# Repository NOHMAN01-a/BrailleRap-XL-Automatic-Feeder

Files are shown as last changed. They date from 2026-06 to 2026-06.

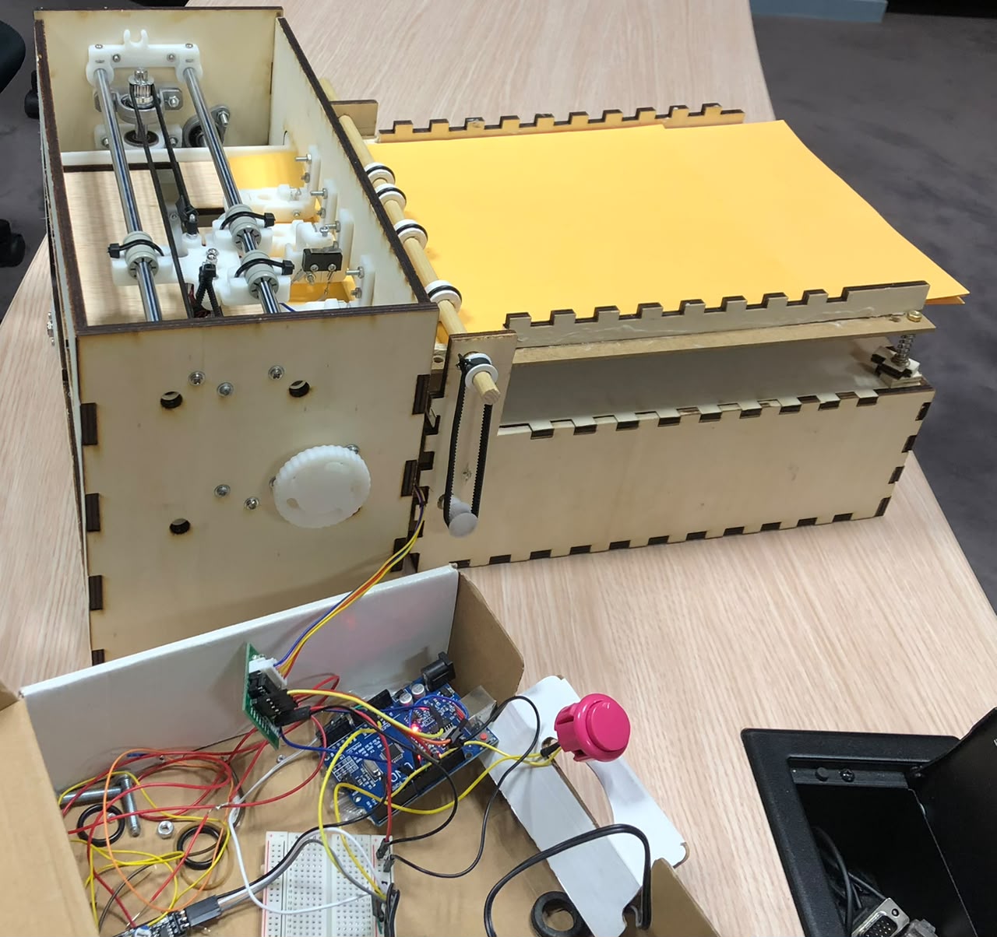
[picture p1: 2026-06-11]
WhatsApp Image 2026-06-10 at 10.59.23 AM (2).jpeg

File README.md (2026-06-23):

# BrailleRap XL Automatic Feeder

Projet réalisé dans le cadre du stage de Master EEA à l'ISTIC - Université de Rennes.

## Travaux réalisés

- Assemblage de la BrailleRap L
- Validation expérimentale sur banc de test
- Optimisation des paramètres de déplacement
- Développement d'un chargeur automatique de feuilles

## Système développé

Le chargeur automatique est constitué :

- d'une carte Arduino ;
- d'un moteur pas à pas 28BYJ-48 ;
- d'un driver ULN2003 ;
- d'un capteur infrarouge de détection ;
- d'un bouton poussoir ;
- d'un rouleau d'entraînement imprimé en 3D ;
- de poulies imprimées en 3D ;
- d'un support en bois découpé au laser ;
- de quatre ressorts assurant la compensation de hauteur de la pile de feuilles.

## Fonctionnement

1. L'utilisateur appuie sur le bouton.
2. Le moteur entraîne le rouleau.
3. La feuille avance vers la BrailleRap L.
4. Le capteur détecte l'arrivée de la feuille.
5. L'Arduino arrête automatiquement le moteur.

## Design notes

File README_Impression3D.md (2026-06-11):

# Pièces imprimées en 3D

## Objectif

Plusieurs composants mécaniques du chargeur automatique ont été réalisés par impression 3D afin de réduire le coût de fabrication et de faciliter les modifications du prototype.

## Composants réalisés

### Rouleau d'entraînement

Le rouleau d'entraînement a été modélisé sous Tinkercad puis fabriqué par impression 3D.

Sa fonction est d'assurer l'entraînement des feuilles vers l'entrée de la BrailleRap XL.

Des joints toriques ont été ajoutés afin d'augmenter l'adhérence entre le rouleau et les feuilles.

### Poulies

Les poulies utilisées pour la transmission du mouvement ont également été modélisées sous Tinkercad puis imprimées en 3D.

Elles permettent de transmettre efficacement le mouvement du moteur vers le rouleau d'entraînement.

### Supports mécaniques

Certaines pièces de fixation et de guidage ont également été réalisées par impression 3D afin de faciliter l'intégration du système au sein du chargeur automatique.

## Avantages de l'impression 3D

L'utilisation de l'impression 3D a permis :

* une fabrication rapide des prototypes ;
* des modifications simples entre les différentes versions ;
* un coût de réalisation réduit ;
* une personnalisation adaptée aux besoins du projet.

## Logiciel utilisé

Les modèles 3D ont été réalisés sous Tinkercad avant leur fabrication par impression 3D.

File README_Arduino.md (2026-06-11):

# Commande Arduino du chargeur automatique

## Composants utilisés

Arduino UNO
 Moteur pas à pas 28BYJ-48
 Driver ULN2003
 Capteur infrarouge de détection
 Bouton poussoir
 Alimentation 5 V

## Connexions

### Bouton poussoir

 Composant | Arduino 
  
 Bouton     D2      
 Bouton     GND     

### Capteur infrarouge

 Capteur  Arduino 
 -------  ------- 
 VCC      5V      
 GND      GND     
 OUT      D3      

### Driver ULN2003

 ULN2003 | Arduino 
 -------  -------
 IN1      D8      
 IN2      D10     
 IN3      D9      
 IN4      D11     

Le moteur 28BYJ-48 est directement connecté au driver ULN2003.

## Principe de fonctionnement

Le système fonctionne selon la séquence suivante :

1. L'utilisateur appuie sur le bouton poussoir.
2. L'Arduino démarre le moteur pas à pas.
3. Le rouleau entraîne une feuille vers l'entrée de la BrailleRap XL.
4. Lorsque la feuille atteint la position souhaitée, le capteur infrarouge la détecte.
5. L'Arduino arrête immédiatement le moteur.
6. La feuille est alors correctement positionnée pour l'impression.

## Description du programme

Le programme utilise la bibliothèque Stepper pour piloter le moteur pas à pas.

Le bouton poussoir permet de lancer un cycle d'alimentation. Une boucle surveille ensuite l'état du capteur infrarouge.

Tant qu'aucune feuille n'est détectée, le moteur continue de tourner. Dès que le capteur détecte la présence de la feuille, l'Arduino arrête le moteur afin de positionner correctement le papier à l'entrée de la machine.

Cette stratégie simple a permis d'obtenir une alimentation feuille par feuille fiable lors des essais réalisés sur le prototype.

## Explication du code

### Bibliothèque Stepper

```cpp
#include <Stepper.h>
```

Permet de piloter le moteur pas à pas à l'aide de la bibliothèque Arduino Stepper.

---

### Nombre de pas du moteur

```cpp
const int stepsPerRevolution = 2048;
```

Définit le nombre de pas nécessaires pour effectuer un tour complet du moteur 28BYJ-48.

---

### Déclaration du moteur

```cpp
Stepper myStepper(stepsPerRevolution, 8, 10, 9, 11);
```

Associe le moteur aux broches de commande du driver ULN2003.

---

### Déclaration des entrées

```cpp
const int buttonPin = 2;
const int sensorPin = 3;
```

Déclare les broches utilisées respectivement pour le bouton poussoir et le capteur infrarouge.

---

### Variable de mémorisation

```cpp
bool lastButtonState = HIGH;
```

Permet de mémoriser l'état précédent du bouton afin de détecter un nouvel appui.

---

### Fonction setup()

```cpp
void setup()
```

Fonction exécutée une seule fois au démarrage de l'Arduino.

```cpp
pinMode(buttonPin, INPUT_PULLUP);
```

Configure le bouton poussoir en entrée avec résistance interne.

```cpp
pinMode(sensorPin, INPUT);
```

Configure le capteur infrarouge en entrée.

```cpp
myStepper.setSpeed(10);
```

Définit la vitesse de rotation du moteur.

---

### Fonction loop()

```cpp
void loop()
```

Fonction exécutée en continu pendant le fonctionnement du système.

---

### Lecture du bouton

```cpp
bool currentButtonState = digitalRead(buttonPin);
```

Lit l'état actuel du bouton poussoir.

---

### Détection d'un appui

```cpp
if (lastButtonState == HIGH && currentButtonState == LOW)
```

Détecte un nouvel appui sur le bouton.

---

### Rotation du moteur

```cpp
while (digitalRead(sensorPin) == HIGH)
{
    myStepper.step(10);
}
```

Le moteur tourne tant que le capteur ne détecte pas la présence d'une feuille.

---

### Détection de la feuille

```cpp
digitalRead(sensorPin)
```

Lit l'état du capteur infrarouge.

* HIGH : aucune feuille détectée.
* LOW : feuille détectée.

---

### Arrêt du moteur

Lorsque le capteur détecte la feuille, la boucle s'arrête automatiquement et le moteur cesse de tourner.

---

### Temporisation

```cpp
delay(300);
```

Ajoute une courte temporisation afin d'éviter plusieurs déclenchements successifs.

---

### Mise à jour de l'état du bouton

```cpp
lastButtonState = currentButtonState;
```

Met à jour l'état précédent du bouton pour préparer le cycle suivant.

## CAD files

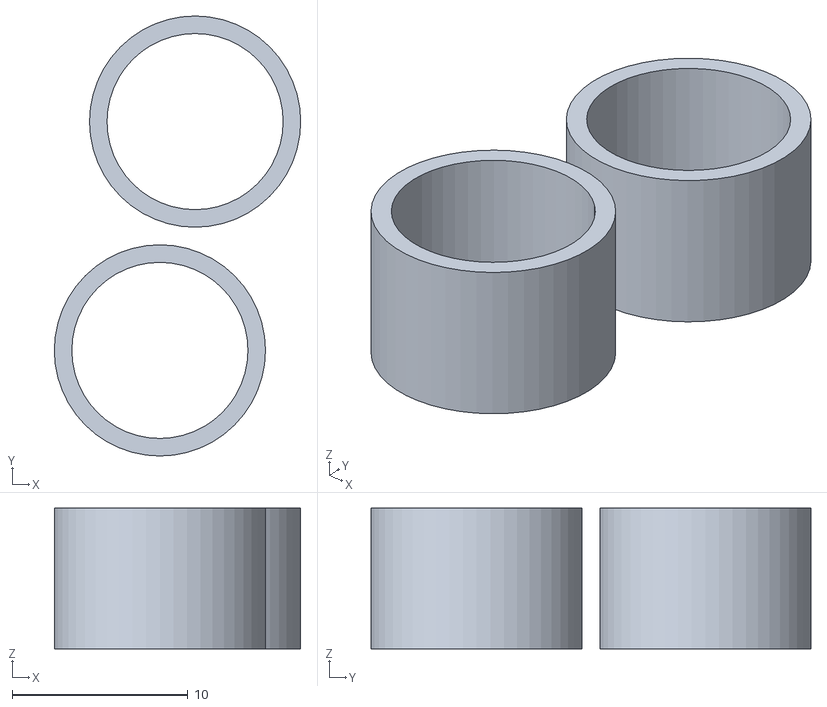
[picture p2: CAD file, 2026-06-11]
cylindre.stl
14.0 x 25.0 x 8.00

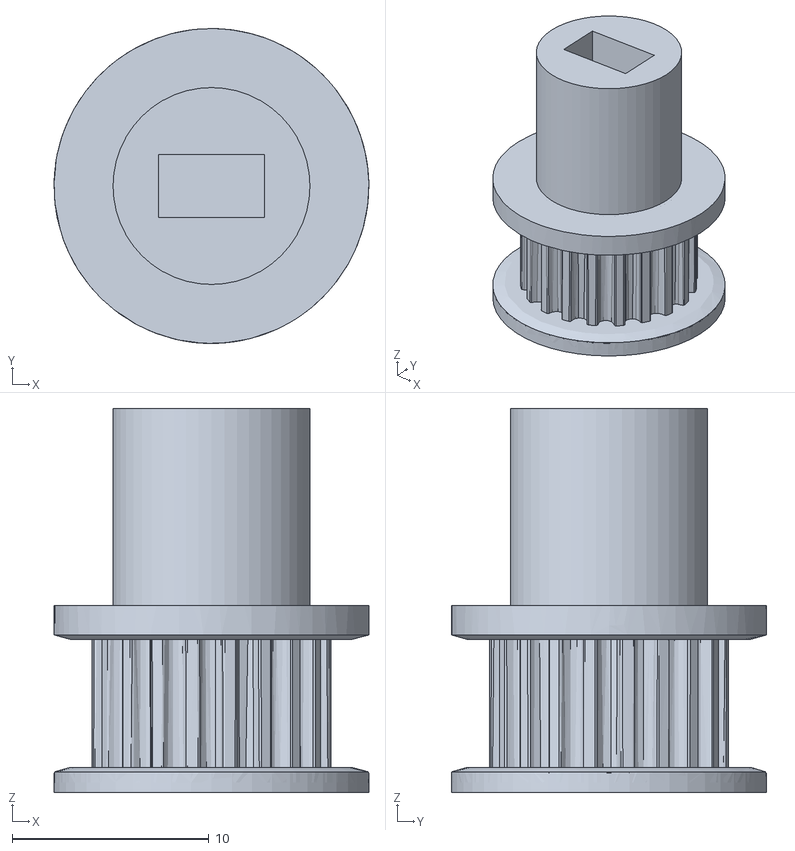
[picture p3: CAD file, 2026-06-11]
poulie-cylindre.stl
16.0 x 16.0 x 19.5

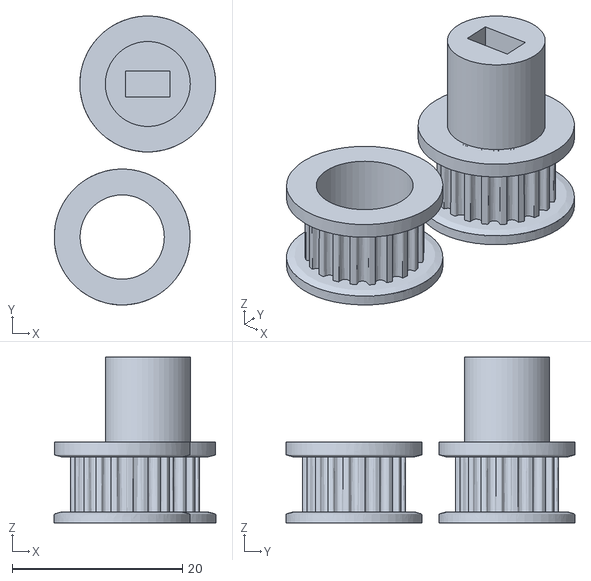
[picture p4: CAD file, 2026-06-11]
poulie.stl
19.0 x 34.0 x 19.5

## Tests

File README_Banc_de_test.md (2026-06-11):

# Banc de test de la BrailleRap XL

## Objectif

Le banc de test a été réalisé afin de déterminer les paramètres optimaux de fonctionnement des axes X et Y avant l'intégration complète sur la BrailleRap XL.

Les essais ont porté principalement sur l'influence du feedrate sur le temps de déplacement, le niveau sonore, la stabilité du mouvement et la précision du retour à la position de référence.

---

# Résultats expérimentaux – Axe X

| Distance (mm) | Feedrate | Temps (s) | Bruit (dB) | Observation |
| --- | --- | --- | --- | --- |
| 50 | 3000 | 1.04 | 53 | Stable |
| 50 | 5000 | 0.70 | 54 | Stable |
| 50 | 8000 | 0.56 | 49 | Stable |
| 50 | 9000 | 0.53 | 50.5 | Stable |
| 50 | 13000 | 0.49 | 51 | Stable |
| 50 | 15000 | 0.40 | 57 | Stable |
| 50 | 18000+ | 0.40 | Variable | Vibrations plus importantes |

## Conclusion Axe X

La valeur F15000 a été retenue comme valeur optimale. Au-delà de cette valeur, aucune amélioration significative n'a été observée et les vibrations augmentent.

---

# Résultats expérimentaux – Axe Y

| Distance (mm) | Feedrate | Temps (s) | Bruit (dB) | Observation |
| --- | --- | --- | --- | --- |
| 100 | 3000 | 2.18 | 51.7 | Stable |
| 100 | 5000 | 1.65 | 47.1 | Stable |
| 100 | 9000 | 1.25 | 55 | Stable |
| 100 | 11000 | 1.00 | 57.5 | Stable |
| 100 | 13000 | 1.00 | 57 | Stable |
| 100 | 15000 | 1.00 | 55 | Stable |

## Conclusion Axe Y

La valeur F11000 a été retenue comme valeur optimale. L'augmentation du feedrate au-delà de cette valeur n'apporte pas d'amélioration supplémentaire.

---

# Validation sur la BrailleRap XL

Les paramètres déterminés sur le banc de test ont ensuite été appliqués à la BrailleRap XL complète.

Les essais réalisés sur la machine ont montré une concordance d'environ 98 % avec les résultats obtenus sur le banc de test, validant ainsi la méthodologie utilisée pour le choix des paramètres de fonctionnement.
